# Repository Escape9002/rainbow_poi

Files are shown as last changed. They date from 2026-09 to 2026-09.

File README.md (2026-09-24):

# Rainbow Poi
Tiny LED's to be swung in circles at high speeds.
Yes, they change color when getting faster.
Yes, you can controll how they change color.
Yes, you can controll what is measured to change color.
Yes, there are more settings.

You can find the controller app here: [rainbow_app](https://github.com/Escape9002/rainbow_app).

## Firmware
This firmware has been written with the help of AI. Every line was read and validated.

### Animation States
Theres an Animation State machine, currently supported are:
- Acceleration
- Gyroscope
- Flashing
- Rainbow
- Constant

Some of these states can be manipulated via the BLE(Bluetooth Low Energy) interface.
You can find the implementation here:
``./lib/PoiController/src/AnimationState``

### Hardware States
The Poi will go to sleep after a configured amount of time (usually 5 minutes), if no motion is detected.
You can wake it with a HARD shake (bonking it on the ground will do it, or against a second poi).
If the Poi starts flashing red, the battery is low. Please recharge asap.

The Hardware State Machine supports these states:
- Idle (waiting for sleep)
- On
- Sleep (shutting down Wifi, BLE, waking at ShakeDetection of IMU)
- LowBattery (if <10% charge remaining, flash red)

### OverTheAir Updates
The Firmware supports OTA updates, I dont yet know how to do this via the rainbow_app, but latery maybe...

## Case
You can find my Case-Design here:
``SimpleCase.FCStd``

Please come up with a better one. 

## Circuit
```text
       [ Li-Ion Battery 3.7V ]
         | +          | -
         |            |
  +------|------------|----------------------+
  |     5V           GND                     |
  |                                          |
  |     A3 (Bat Lvl) <-----[ V-Divider ]-----+
  |                                          |
  |         [ESP32-C3 SuperMini]             |
  |                                          |
  |  GPIO2 (LED Data) -----------------------> [ WS2812B LED Strip (15x) ]
  |  GPIO8 (Status LED)                      |
  |                                          |
  |  GPIO4 (IMU_INT) <-----------+           |
  |  GPIO5 (SCL) <------------+  |           |
  |  GPIO6 (SDA) <---------+  |  |           |
  |                        |  |  |           |
  +------------------------|--|--|-----------+
                           |  |  |
                        +--|--|--|-+
                        | SDA    | |
                        | SCL  INT |
                        | [MPU9250]|
                        |  9-DOF   |
                        +----------+
```

- **LED-Strip**:
    powered directly from the battery
- **Battery**:
    Choosing Lithium-ion since current drain rate is high enough for MCU and LEDs, while not being a handgranate in high impact scenarios (looking at you, LiPo). I got these ones: [Jesspow CR123A](https://jesspow.com/products/cr123a-rechargeable-li-ion-battery-4-pack)
- **Voltage Divider**: 
    consists of 2x10k Ohm resistors, to ensure that the analog pin of the ESP can measure the up to 4V of the battery.

Since my battery is mounted on a different PCB, I "insulated" the backside of the main PCB with some tape.

# Pictures

> You can find all the pics in the ``img`` folder

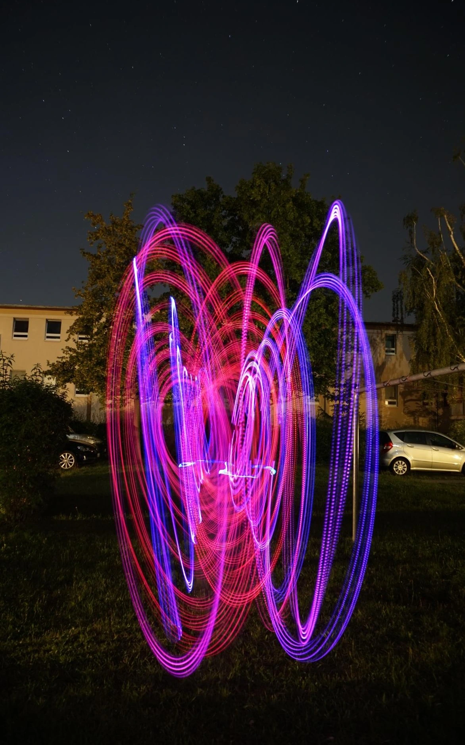
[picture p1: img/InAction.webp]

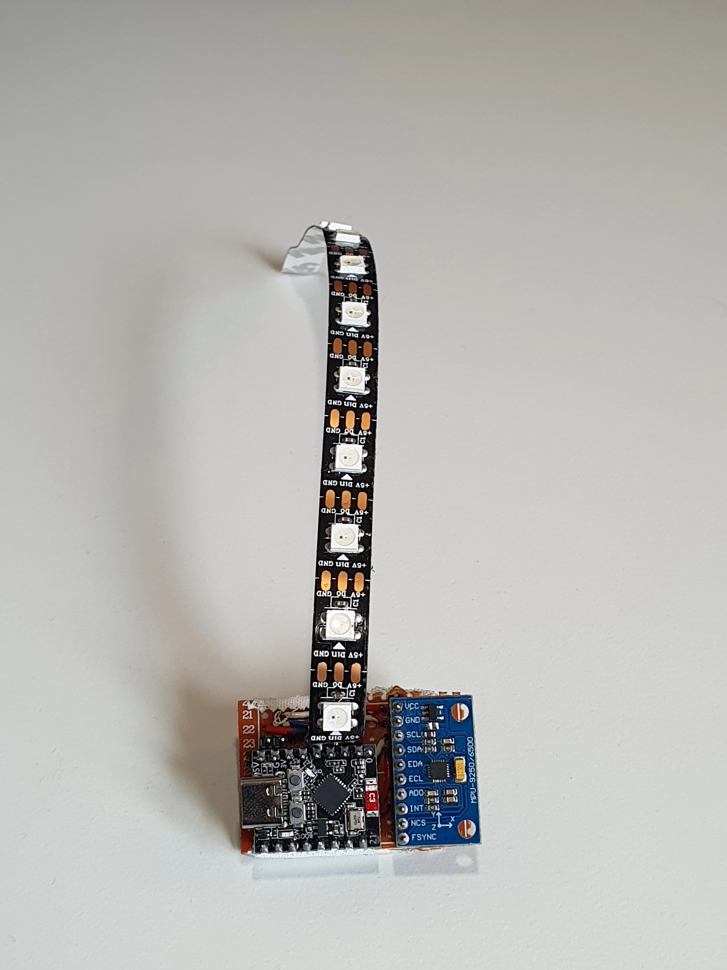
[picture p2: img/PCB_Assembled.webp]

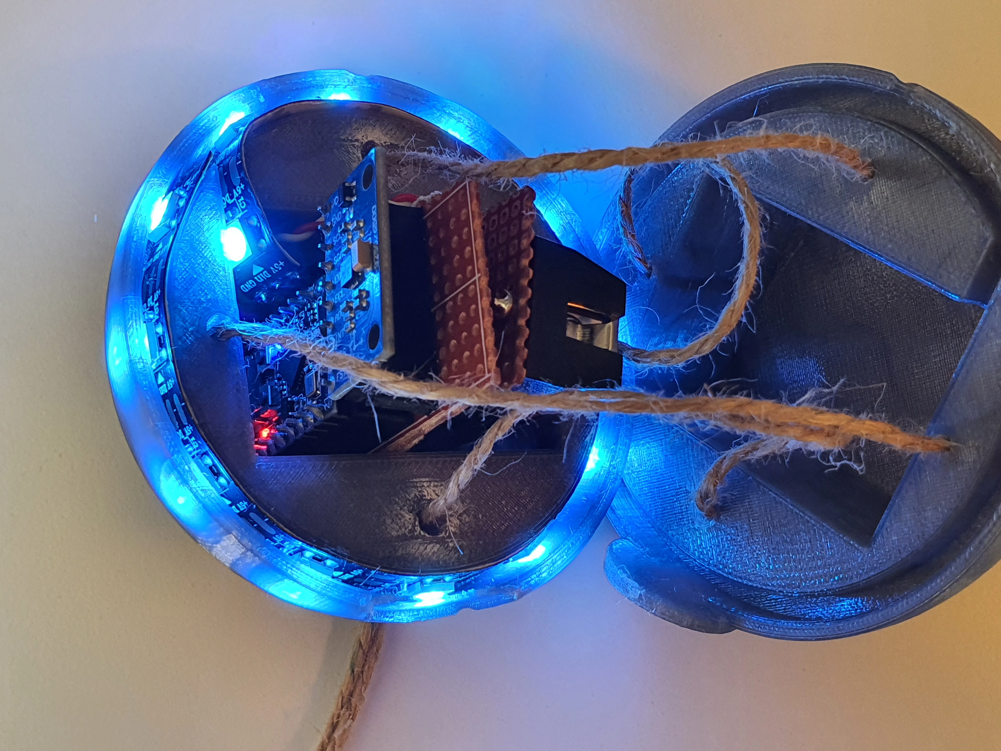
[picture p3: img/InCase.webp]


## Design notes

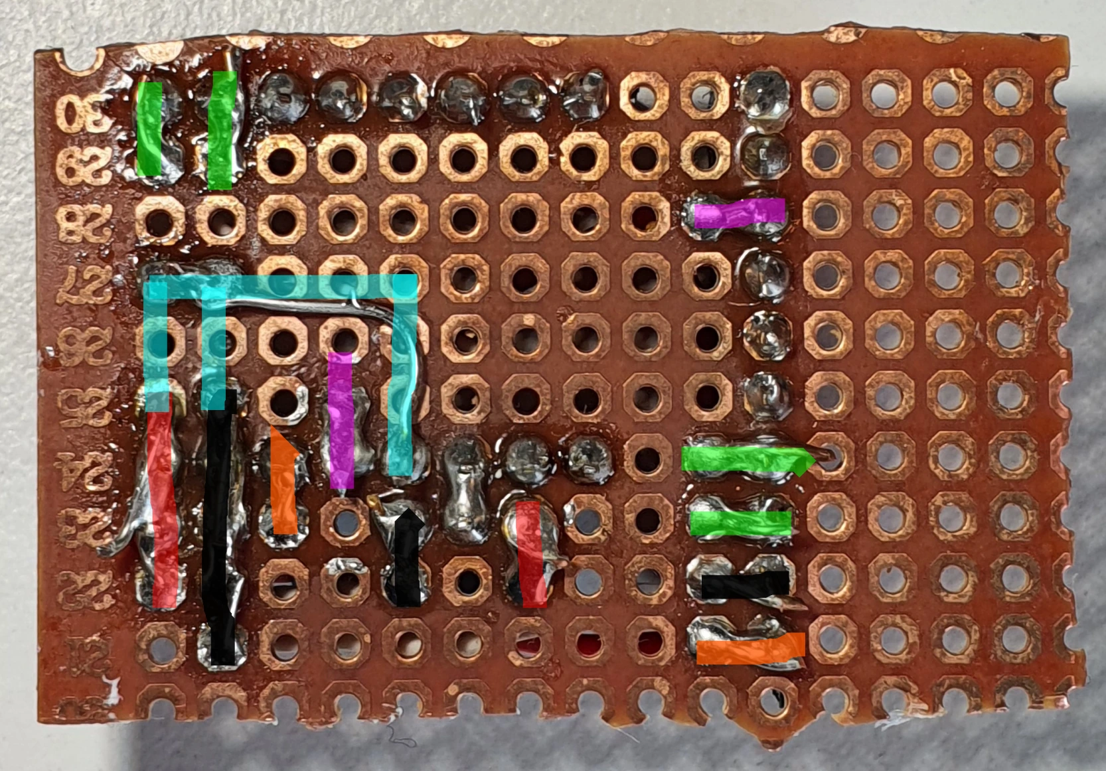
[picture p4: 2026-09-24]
img/PCB_Lower_Marked.webp

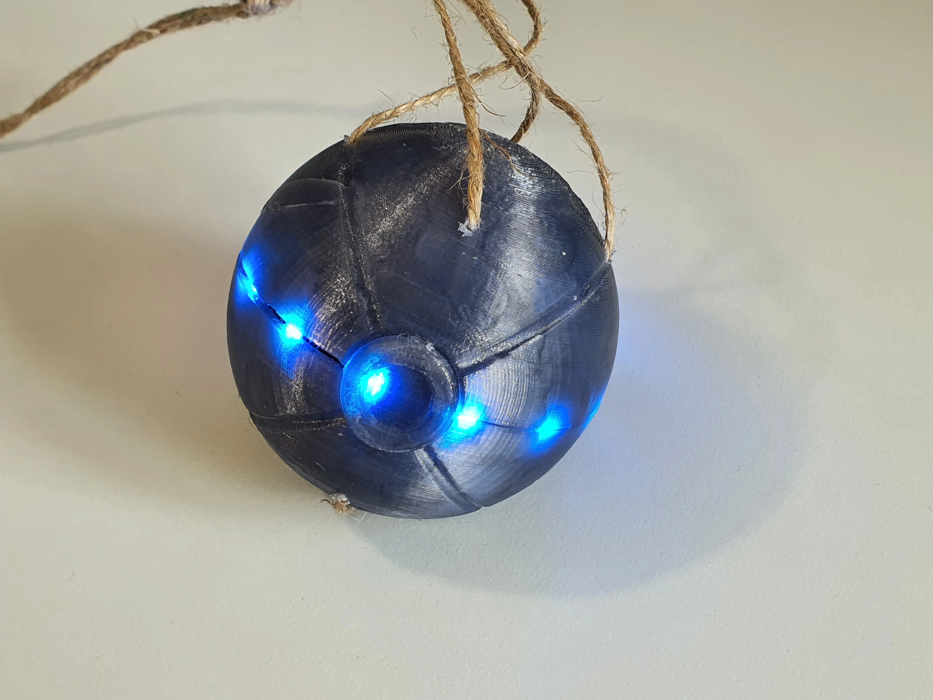
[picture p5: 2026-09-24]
img/InCaseClosed.webp

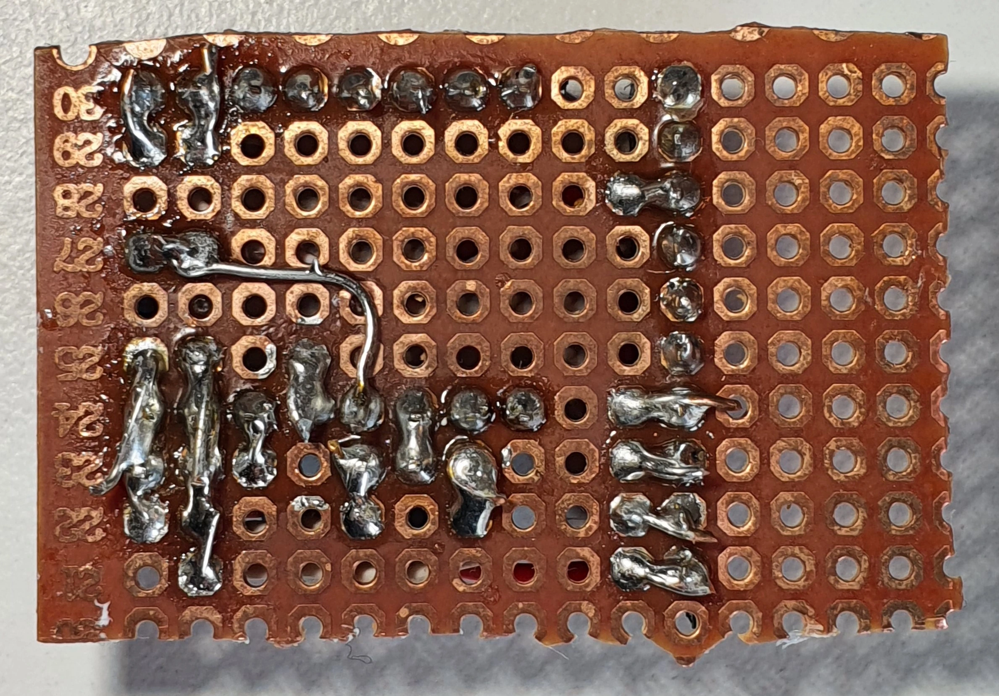
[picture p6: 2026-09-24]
img/PCB_Lower.webp

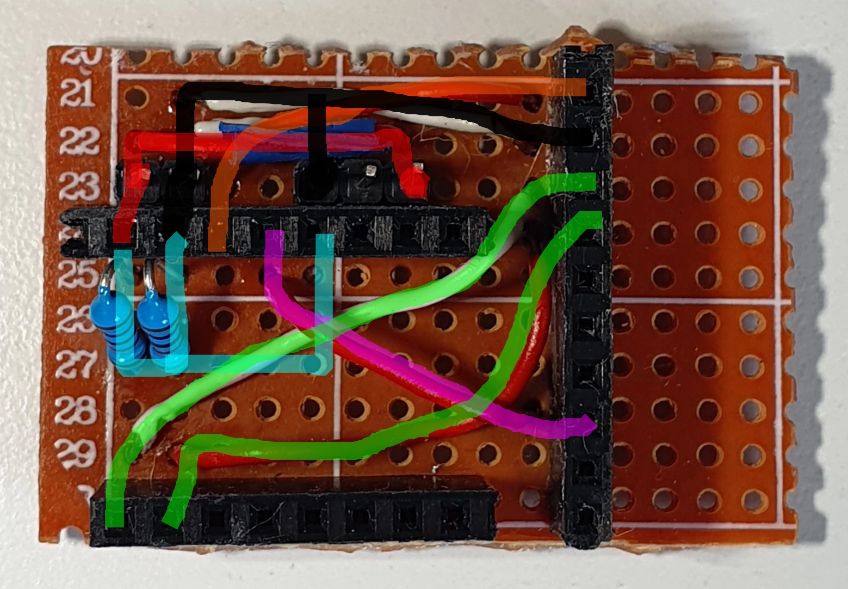
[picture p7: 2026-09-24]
img/PCB_Upper_Marked.webp

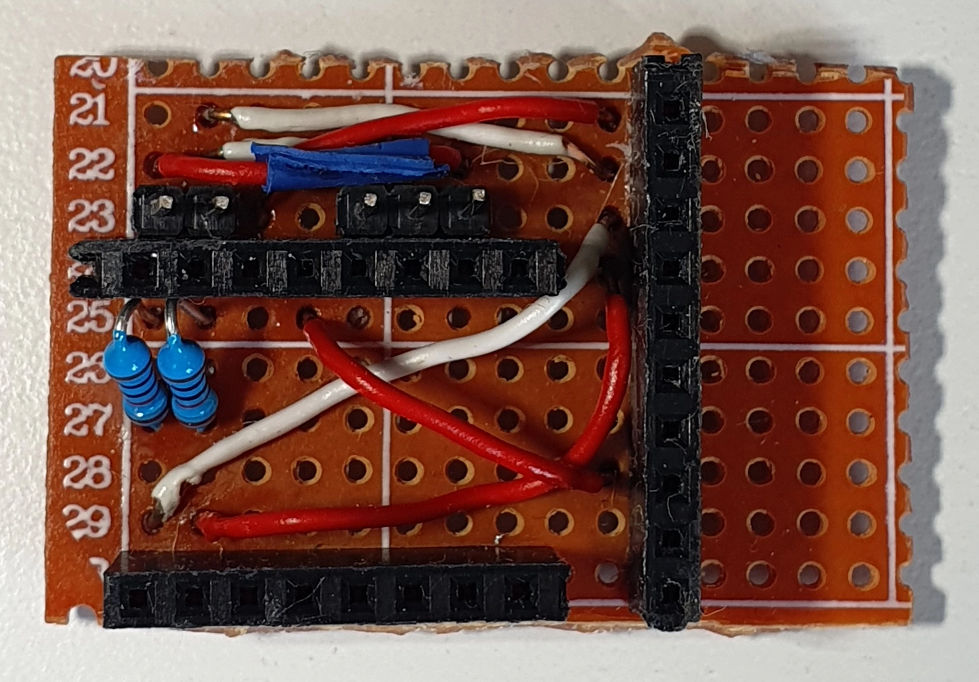
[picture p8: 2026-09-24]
img/PCB_Upper.webp

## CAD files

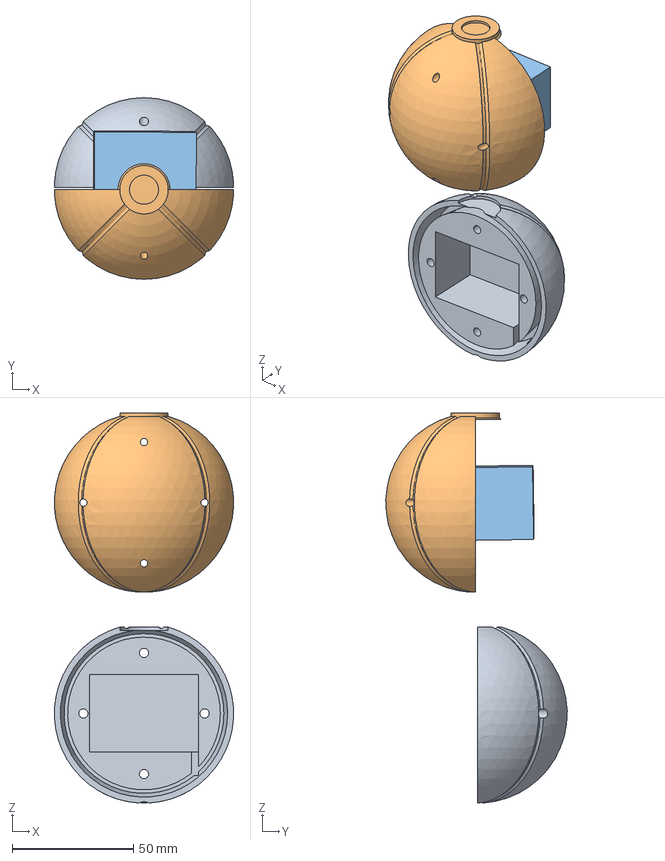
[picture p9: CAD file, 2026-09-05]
SimpleCase.FCStd
73.9 x 75.0 x 160.9 mm
LowerHalf
UpperHalf
LePCB

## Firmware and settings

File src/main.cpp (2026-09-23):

#include <Arduino.h>
#include <Wire.h>
#include <math.h>
#include <vector>
#include "mpu9250.h"
#include "esp_sleep.h"
#include <driver/gpio.h>
#include "soc/rtc_cntl_reg.h"

#include <FastLED.h>

#include <HSV.h>
#include <LowPass.h>
#include <ESP32C3SuperMini.h>
#include <Preferences.h>
// ============================================================
// HARDWARE CONFIGURATION
// ============================================================

// ESP32-C3 SuperMini
#define IMU_SDA_PIN 6
#define IMU_SCL_PIN 5
#define IMU_INT_PIN 4

// FastLED
#define NUM_LEDS 15
#define DATA_PIN 2
#define LED_BRIGHTNESS 255

// Status LED
#define STATUS_LED_PIN 8

#define VOLTAGE_DIVIDER_FACTOR 2
#define BATTERY_MEASUREMENT_PIN 3
const uint16_t CHARGE_CUTOFF_V = 4200;    // mV
const uint16_t DISCHARGE_CUTOFF_V = 3230; // mV
uint16_t chargePercentage = 100;

// ============================================================
// OTA CONFIG
// ============================================================

#define OTA 1
#if OTA
#include <WiFi.h>
#include <ArduinoOTA.h>
#include <OTAConfig.h>

const char *ssid = "000";      // Specify your WiFi SSID
const char *password = "0000"; // Specify your WiFi Password

Preferences preferences;
OTASettings savedSettings = {"", "", ""};
#endif

#define PRODUCTION_RELEASE 1
#if !PRODUCTION_RELEASE
#include "LocalOTA.h"

#endif

// ============================================================
// RESET REASON LOGGER
// ============================================================
#define RESET_LOGGER 0
#if RESET_LOGGER
#include "esp_system.h" // Needed for esp_reset_reason()
#include <soc/soc.h>

struct BootLogEntry
{
    esp_reset_reason_t reset_reason;
};

constexpr uint8_t MAX_LOG_ENTRIES = 16; // 16 entries is plenty and uses < 200 bytes

// Helper to convert esp_reset_reason_t to readable text
const char *resetReasonToString(esp_reset_reason_t reason)
{
    switch (reason)
    {
    case ESP_RST_POWERON:
        return "POWER_ON";
    case ESP_RST_EXT:
        return "EXTERNAL_PIN";
    case ESP_RST_SW:
        return "SOFTWARE_RESTART";
    case ESP_RST_PANIC:
        return "CRASH / PANIC (EXCEPTION)";
    case ESP_RST_INT_WDT:
        return "INTERRUPT_WATCHDOG";
    case ESP_RST_TASK_WDT:
        return "TASK_WATCHDOG (FREEZE)";
    case ESP_RST_WDT:
        return "OTHER_WATCHDOG";
    case ESP_RST_DEEPSLEEP:
        return "DEEP_SLEEP_WAKE";
    case ESP_RST_BROWNOUT:
        return "BROWNOUT (VOLTAGE DROP)";
    case ESP_RST_SDIO:
        return "SDIO";
    default:
        return "UNKNOWN";
    }
}

void logAndPrintBootDiagnostics()
{
    esp_reset_reason_t reset_reason = esp_reset_reason();

    BootLogEntry history[MAX_LOG_ENTRIES];
    uint8_t count = 0;
    uint32_t total_boots = 0;

    preferences.begin("boot_diag", false);

    // Read previous boot count
    total_boots = preferences.getUInt("total_boots", 0);
    total_boots++;
    preferences.putUInt("total_boots", total_boots);

    // Read previous logs
    if (preferences.getBytesLength("logs") == sizeof(history))
    {
        preferences.getBytes("logs", history, sizeof(history));
        count = preferences.getUChar("count", 0);
    }
    else
    {
        memset(history, 0, sizeof(history));
    }

    // Print Historical Logs to Serial
    Serial.println("\n========== BOOT DIAGNOSTIC HISTORY ==========");
    Serial.printf("Lifetime Total Boots: %u\n", total_boots);
    Serial.println("----------------------------------------------");
    for (uint8_t i = 0; i < count; i++)
    {
        Serial.printf("#%02d, %-25s\n",
                      i + 1,
                      resetReasonToString(history[i].reset_reason));
    }
    Serial.println("----------------------------------------------");
    Serial.printf("CURRENT BOOT: Reset Reason: %s \n",
                  resetReasonToString(reset_reason));
    Serial.println("==============================================\n");

    // Push new entry into our circular array (shift oldest out if full)
    if (count < MAX_LOG_ENTRIES)
    {
        history[count] = {reset_reason};
        count++;
    }
    else
    {
        // Shift left: drop oldest, add newest at end
        for (uint8_t i = 0; i < MAX_LOG_ENTRIES - 1; i++)
        {
            history[i] = history[i + 1];
        }
        history[MAX_LOG_ENTRIES - 1] = {reset_reason};
    }

    // Save back to Flash
    preferences.putBytes("logs", history, sizeof(history));
    preferences.putUChar("count", count);
    preferences.end();
}
#endif
// ============================================================
// MPU9250
// ============================================================
/* Mpu9250 object, I2C bus,  0x68 address */
bfs::Mpu9250 imu(&Wire, bfs::Mpu9250::I2C_ADDR_PRIM);

// ============================================================
// BLE
// ============================================================
#define BLE 1
#if BLE
#include <BLEServer.h>
#include <BleEndpoint.h>
#include "FastLEDEffects.h"

#define BLE_DEVICE_NAME "POI"

#define BLE_SERVICE_UUID \
    "c5b6fc84-1450-4f82-83c7-ef4dc0e948de"

#define ALPHA_UUID \
    "309d5cfd-4ad1-45f6-81c8-fd6f512ae200"
#define BATTERY_CHAR_UUID "2A19" // Standard BLE Battery Level UUID
#define HUE_MIN_UUID \
    "f79431f4-255a-400e-a9d4-63c0d5be5e2a"
#define HUE_MAX_UUID \
    "f789580d-1fd5-4579-bf3f-18db5adc6b3e"
#define CONTROLLER_MODE_UUID \
    "bbe6c883-f669-4fa8-b110-808feb345e75"

#define OTA_SSID_UUID "5fddf75c-642e-4680-a28f-ff170e95eb62"
#define OTA_SSID_PWD "1dc9ae9c-6d6a-47f3-b1f3-3d75cb8bb801"
#define OTA_PWD "77436d8a-2068-4fa3-9563-91c62339909f"

// 1. Create the server instance
BleServer bleServer(BLE_SERVICE_UUID);
// 2. Create our custom typed endpoint (initial value: 80)
BleEndpoint<uint32_t> endpointAlpha(ALPHA_UUID, "filter_alpha", 80, NIMBLE_PROPERTY::READ | NIMBLE_PROPERTY::WRITE);
BleEndpoint<uint16_t> endpointHueMin(HUE_MIN_UUID, "hueMin", 260, NIMBLE_PROPERTY::READ | NIMBLE_PROPERTY::WRITE);
BleEndpoint<uint16_t> endpointHueMax(HUE_MAX_UUID, "hueMax", 359, NIMBLE_PROPERTY::READ | NIMBLE_PROPERTY::WRITE);
BleEndpoint<std::string> endpointCntrlMde(CONTROLLER_MODE_UUID, "CntrlMde", "GYRO", NIMBLE_PROPERTY::READ | NIMBLE_PROPERTY::WRITE);

BleEndpoint<std::string> endpointSSID(OTA_SSID_UUID, "SSID", "1234",  NIMBLE_PROPERTY::WRITE);
BleEndpoint<std::string> endpointWifiPwd(OTA_SSID_PWD, "WIFI_PWD", "1234", NIMBLE_PROPERTY::WRITE);
BleEndpoint<std::string> endpointOTAPwd(OTA_PWD, "OTA_PWD", "1234", NIMBLE_PROPERTY::WRITE);

// Typ: uint8_t | Startwert: 100% | Rechte: Lesen & Benachrichtigen (Kein Schreiben vom Handy!)
BleEndpoint<uint8_t> endpointBattery(
    BATTERY_CHAR_UUID,
    "BatteryLvl",
    100,
    NIMBLE_PROPERTY::READ | NIMBLE_PROPERTY::NOTIFY);
#endif
// ============================================================
// FASTLED
// ============================================================

CRGB leds[NUM_LEDS];

// ============================================================
// FIXED POINT CONFIGURATION
// ============================================================
//
// All acceleration values use:
//
//      real value * 1000
//
// Example:
//
//      0.5 m/s^2  -> 500
//      1.0 m/s^2  -> 1000
//      9.81 m/s^2 -> 9810
//      18 m/s^2   -> 18000
//
// This gives us 3 decimal places.
// ============================================================

#define FP_SCALE 1000UL

// ============================================================
// PHYSICAL CONSTANTS
// ============================================================

// Gravity
#define GRAVITY_MSS 9810UL

// Ignore acceleration below 0.5 m/s^2
#define DEADZONE_MSS 1000UL

// Minimum acceleration required to reset sleep timer
#define MINIMUM_ACCL_MSS DEADZONE_MSS

// ============================================================
// AUTOMATIC ACCELERATION RANGE
// ============================================================
//
// Initial value:
//     18 m/s^2
// ============================================================

uint32_t MAX_ACCL_MSS = 18000;

uint32_t MAX_GYRO_RADS = 200;

// ============================================================
// LED UPDATE
// ============================================================

#define LED_UPDATE_MS 5UL

uint32_t lastLedUpdate = 0;

FastLEDEffects realEffectEngine;

// ============================================================
// GET ACCELERATION MAGNITUDE
// ============================================================
//
// Returns dynamic acceleration in:
//
//     milli m/s^2
//
// Example:
//
//     0.5 m/s^2 -> 500
//     5.0 m/s^2 -> 5000
//
// Gravity is removed by:
//
//     abs(|a| - 9.81)
// ============================================================

uint32_t getAbsoluteAcceleration()
{
    // --------------------------------------------------------
    // Convert sensor floats into fixed-point integers
    // --------------------------------------------------------

    int32_t ax =
        (int32_t)(imu.accel_x_mps2() * FP_SCALE);

    int32_t ay =
        (int32_t)(imu.accel_y_mps2() * FP_SCALE);

    int32_t az =
        (int32_t)(imu.accel_z_mps2() * FP_SCALE);

    // --------------------------------------------------------
    // Calculate:
    //
    // sqrt(ax^2 + ay^2 + az^2)
    //
    // --------------------------------------------------------

    uint64_t sum = (int64_t)ax * ax + (int64_t)ay * ay + (int64_t)az * az;
    uint32_t magnitude = (uint32_t)sqrt((double)sum);

    // --------------------------------------------------------
    // Remove gravity
    // --------------------------------------------------------

    uint32_t movement;

    if (magnitude > GRAVITY_MSS)
    {
        movement =
            magnitude - GRAVITY_MSS;
    }
    else
    {
        movement =
            GRAVITY_MSS - magnitude;
    }

    return movement;
}

uint32_t getAbsoluteRadS()
{
    int32_t ax =
        (int32_t)(imu.gyro_x_radps() * FP_SCALE);

    int32_t ay =
        (int32_t)(imu.gyro_y_radps() * FP_SCALE);

    int32_t az =
        (int32_t)(imu.gyro_z_radps() * FP_SCALE);

    // --------------------------------------------------------
    // Calculate:
    //
    // sqrt(ax^2 + ay^2 + az^2)
    //
    // --------------------------------------------------------

    uint64_t sum = (int64_t)ax * ax + (int64_t)ay * ay + (int64_t)az * az;
    uint32_t magnitude = (uint32_t)sqrt((double)sum);

    return magnitude;
}

// ============================================================
// UPDATE LEDS
// ============================================================

void updateLEDs(
    HSV hsv)
{

    CRGB color = CHSV(
        hsv.hue,
        hsv.saturation,
        hsv.brightness);

    for (uint8_t i = 0; i < NUM_LEDS; i++)
    {
        leds[i] = color;
    }

    FastLED.show();
}

// ============================================================
// GET BATTTERY PERCENTAGE
// ============================================================

uint8_t getBatteryPercentage()
{

    uint16_t volt = analogReadMilliVolts(BATTERY_MEASUREMENT_PIN) * VOLTAGE_DIVIDER_FACTOR;

    // 1. Clamp the voltage to our known bounds to prevent math errors
    if (volt > CHARGE_CUTOFF_V)
        volt = CHARGE_CUTOFF_V;
    if (volt < DISCHARGE_CUTOFF_V)
        volt = DISCHARGE_CUTOFF_V;

    return static_cast<uint8_t>(((volt - DISCHARGE_CUTOFF_V) * 100) / (CHARGE_CUTOFF_V - DISCHARGE_CUTOFF_V));
}

// ============================================================
// POI_CONTROLLER
// ============================================================
#include <PoiController.h>
ESP32C3SuperMini esp32_c3_superMini = ESP32C3SuperMini(&imu, IMU_INT_PIN);
PoiController poi_controller = PoiController(
    realEffectEngine,
    esp32_c3_superMini);

// ============================================================
// SETUP
// ============================================================

void setup()
{
    // --------------------------------------------------------
    // Serial
    // --------------------------------------------------------

    Serial.begin(115200);

#if RESET_LOGGER
    while (!Serial.available())
    {
        delay(100);
    }
    Serial.flush();
    delay(100);
    logAndPrintBootDiagnostics();

    while (!Serial.available())
    {
        delay(10000);
    }
#endif

    Serial.println();
    Serial.println("==============================");
    Serial.println("ESP32-C3 POI");
    Serial.println("==============================");

    setCpuFrequencyMhz(80);

    // --------------------------------------------------------
    // GPIO
    // --------------------------------------------------------
    pinMode(IMU_INT_PIN, INPUT_PULLDOWN);

    pinMode(STATUS_LED_PIN, OUTPUT);
    pinMode(A3, INPUT);

    // Status LED on
    digitalWrite(STATUS_LED_PIN, LOW);

    // --------------------------------------------------------
    // Check battery levels and report to controller
    // --------------------------------------------------------
    // the controller must do a tick to update its hardware states!
    // otherwise the default values persist!

    poi_controller.setBatteryLevel(getBatteryPercentage());

    // --------------------------------------------------------
    // Determine wake reason
    // --------------------------------------------------------
    esp_sleep_wakeup_cause_t wakeup_cause = esp_sleep_get_wakeup_cause();
    if (wakeup_cause == ESP_SLEEP_WAKEUP_GPIO)
    {
        Serial.println("Wakeup: Motion");
    }
    else if (wakeup_cause == ESP_SLEEP_WAKEUP_TIMER)
    {
        Serial.println("Wakeup: Timer");
        // we should check the battery and return to sleep if the charge is high enough.
        // otherwise we should start flashing red.
        // this should be handled by the battery check at the start of the setup function
    }
    else
    {
        Serial.println("Wakeup: POWER ON / RESET | DEFAULT");
        Serial.println(wakeup_cause);
    }
// --------------------------------------------------------
// OTA - PREPERATION
// --------------------------------------------------------
// loading the values from flash here, since the brownout detector
// will be disabled later on. This might corrupt flash, which is why
// we read it here.
#if OTA
    preferences.begin("ota", false); // Separate namespace from "poi"

#if PRODUCTION_RELEASE
    if (preferences.getBytesLength("cfg") == sizeof(OTASettings))
    {
        preferences.getBytes("cfg", &savedSettings, sizeof(OTASettings));
    }
#else
    // C++ requires strncpy for char arrays!
    strncpy(savedSettings.ssid, localSettings.ssid, sizeof(savedSettings.ssid));
    strncpy(savedSettings.pwd, localSettings.pwd, sizeof(savedSettings.pwd));
    strncpy(savedSettings.ota_pwd, localSettings.ota_pwd, sizeof(savedSettings.ota_pwd));
#endif
#endif

    /**
     * Disabling the brownout detector is bad, buuuuut i dont want to buy capacitors.
     * The detector will be turned on after the setup again.
     * It SHOULD be safe :3
     *
     * Remove ASAP (aka, get money and a capacitor)
     *
     * The WIFI/bluetooth part should be the only thing where the brownout detector might trigger.
     * I am only activating it for this time.
     *
     * Sources:
     * - https://www.espboards.dev/troubleshooting/issues/power/esp32-brownout-reset/
     * - https://embeddedprep.com/esp32-brownout-tutorials/
     */
    WRITE_PERI_REG(RTC_CNTL_BROWN_OUT_REG, 0); // disable brownout detector
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
void loop()
{
    digitalWrite(STATUS_LED_PIN, LOW);

#if OTA
    if (WiFi.status() == WL_CONNECTED)
    {
        ArduinoOTA.handle();
    }
#endif

    static uint32_t latest_accl = 0;
    static uint32_t latest_gyro = 0;

    // --------------------------------------------------------
    // Read IMU
    // --------------------------------------------------------
    if (imu.Read())
    {
        latest_accl = getAbsoluteAcceleration();
        latest_gyro = getAbsoluteRadS();
    }

    // ----------------------------------------------------
    // LED update
    // ----------------------------------------------------

    uint32_t now = millis();
    if (
        now - lastLedUpdate >= LED_UPDATE_MS)
    {

        uint32_t dt_ms = now - lastLedUpdate;
        lastLedUpdate = now;

        // Figure out which sensor value the controller cares about right now
        // (If the mode is LOW_BATTERY or CONSTANT, the controller ignores this value anyway)
        uint32_t sensor_value = (poi_controller.getAnimationState() == ANIMATION_STATE::GYRO)
                                    ? latest_gyro
                                    : latest_accl;

        HSV hsv = poi_controller.tick(sensor_value, dt_ms);
        updateLEDs(hsv);

        if (poi_controller.getAnimationState() == ANIMATION_STATE::GYRO)
        {
            Serial.println(sensor_value);
        }
    }

    // ========================================================
    // BATTERY POWER
    // ========================================================

    static uint32_t lastUpdate = 0;
    if (millis() - lastUpdate > 5000)
    {
        lastUpdate = millis();

        poi_controller.setBatteryLevel(getBatteryPercentage());
    }

    // ========================================================
    // BLE
    // ========================================================

#if BLE
    if (poi_controller.getHardwareState() != HARDWARE_STATE::LOW_BATTERY && poi_controller.getHardwareState() != HARDWARE_STATE::SLEEP)
    {
        // Pusht den neuen Wert per Notify direkt auf das Handy!
        if (chargePercentage != endpointBattery.getValue())
        {
            endpointBattery.setValue(chargePercentage);
        }

        if (!bleServer.update().empty())
        {
            // TODO changed endpoint receiver
            // 5. Read the value directly and safely
            uint32_t newAlpha = endpointAlpha.getValue();

            if (newAlpha != poi_controller.getAlpha())
            {
                poi_controller.setAlpha(newAlpha);
                Serial.printf("[MAIN] Alpha updated to: %d\n", poi_controller.getAlpha());
            }

            uint16_t newHueMin = endpointHueMin.getValue();
            if (newHueMin != poi_controller.getHueMin())
            {
                poi_controller.setColorRange(newHueMin, poi_controller.getHueMax());
                Serial.printf("[MAIN] hueMin updated to: %d\n", poi_controller.getHueMin());
            }

            uint16_t newHueMax = endpointHueMax.getValue();
            if (newHueMax != poi_controller.getHueMax())
            {
                poi_controller.setColorRange(poi_controller.getHueMin(), newHueMax);
                Serial.printf("[MAIN] hueMAx updated to: %d\n", poi_controller.getHueMax());
            }

            std::string currentMode = endpointCntrlMde.getValue();
            ANIMATION_STATE requestedState = animationStringToState(currentMode);

            if (poi_controller.getAnimationState() != requestedState)
            {
                poi_controller.setAnimationState(requestedState);

                endpointCntrlMde.setValue(toString(poi_controller.getAnimationState()));
                Serial.printf("[MAIN] AnimState updated to: %s\n", toString(poi_controller.getAnimationState()));
            }

            bool ota_changed = false;

            // Handle OTA SSID
            std::string newSsid = endpointSSID.getValue();
            if (!newSsid.empty() && newSsid != std::string(savedSettings.ssid))
            {
                strncpy(savedSettings.ssid, newSsid.c_str(), sizeof(savedSettings.ssid) - 1);
                savedSettings.ssid[sizeof(savedSettings.ssid) - 1] = '\0'; // Guarantee null termination
                ota_changed = true;
            }

            // Handle OTA WiFi Password
            std::string newPwd = endpointWifiPwd.getValue();
            if (!newPwd.empty() && newPwd != std::string(savedSettings.pwd))
            {
                strncpy(savedSettings.pwd, newPwd.c_str(), sizeof(savedSettings.pwd) - 1);
                savedSettings.pwd[sizeof(savedSettings.pwd) - 1] = '\0';
                ota_changed = true;
            }

            // Handle OTA Password
            std::string newKey = endpointOTAPwd.getValue();
            if (!newKey.empty() && newKey != std::string(savedSettings.ota_pwd))
            {
                strncpy(savedSettings.ota_pwd, newKey.c_str(), sizeof(savedSettings.ota_pwd) - 1);
                savedSettings.ota_pwd[sizeof(savedSettings.ota_pwd) - 1] = '\0';
                ota_changed = true;
            }

            // Save to Flash
            if (ota_changed)
            {
                preferences.putBytes("cfg", &savedSettings, sizeof(OTASettings));
                Serial.println("[BLE] OTA Settings updated and saved to Flash!");
            }
        }
    }

    // turn at least tripple the amount the LED needs to render.
    delay(LED_UPDATE_MS / 3);

#endif
}

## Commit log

2026-08-29 first simple case design
    [SimpleCase.FCStd]
2026-08-29 switched to spheres
    [SimpleCase.FCStd]
2026-08-29 added wire helpers
    [SimpleCase.FCStd]
2026-08-29 added poke vibes
    [SimpleCase.FCStd]
2026-08-31 some minor changes
    [SimpleCase.FCStd]
2026-08-31 corrected case size, added FCbak to ignore
    [SimpleCase.FCStd]
2026-08-31 added lowpass filter
2026-08-31 fixed LED-channel
    [SimpleCase.FCStd]
2026-09-01 Revert changes back to fe6b2b2; old case design was correct
    [SimpleCase.FCStd]
2026-09-01 updated case to fit
    [SimpleCase.FCStd]
2026-09-02 disable BLE for powersavings/brownout
    [main.cpp]
2026-09-02 fast led uses uint8, we use uint16, added adapter between fastLED and us
2026-09-04 minor changes
    [SimpleCase.FCStd]
2026-09-04 added voltage read + report
2026-09-05 added flashing mode for low battery times
2026-09-05 make led flicker a little less (doesnt work. limit is led strip)
2026-09-05 status LED on first please
2026-09-05 wire should go through entire thing, added holes for that
    [SimpleCase.FCStd]
2026-09-05 added ble/battery power workaround
    [main.cpp]
2026-09-07 added gyro mode
2026-09-07 correct SRD computation, add handler for sleepy battery checks
    [main.cpp]
2026-09-08 added timer_wakeup in deepsleep mode
2026-09-10 cleaned up toString, added missing states, checked constructors
    [main.cpp]
2026-09-10 replaced pointers for states with enums
    [main.cpp]
2026-09-10 removed getAnimator(), replaced with switch -> enum controll
2026-09-11 minor cleanup and added flashing to the battery state
2026-09-11 made dedicated Ticks public again. found load access fault bug
    [main.cpp]
2026-09-11 fix LED at highest brightness
    [main.cpp]
2026-09-11 minor issues, reconfigure power settings for BLE
2026-09-21 Revert "enabled perma storage for config"
    This reverts commit 3ce4a990ccb6bf803c8ef4295c4c9f72b05ebc0d.
    delete perma-storage as requested in issue #28
    [main.cpp]
2026-09-21 some power optimizations
2026-09-23 i2c bug fixed
2026-09-23 hotfix: disable brownout detector
    [main.cpp]
2026-09-23 sort hotfix to prevent flash corruption, enable sleep, enable full brightness
    [main.cpp]
